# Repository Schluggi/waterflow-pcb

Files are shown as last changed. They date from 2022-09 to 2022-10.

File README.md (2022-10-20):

# waterflow-pcb


<a href="https://www.buymeacoffee.com/schluggi" target="_blank">Buy Me A Coffee</a>

## Description
I love the idea of GreatScott`s [Online Water Tracker](https://www.youtube.com/watch?v=BNK92ep8DhY), but unfortunately
it was really difficult for me to implement his circuit on a perfboard, so I designed a cheap PCB for this.

> Please notice, that this board does not replace/include the charge circuit (TP4056) or the boost converter. It
> only replaces the big ESP circuit.

The PCB has also some improvements:
- Connection terminals to easily (dis)connect everything
- Extra connection for a waterflow-sensors [with a temperature sensor](https://smile.amazon.de/gp/product/B07QNN1N7W/ref=ppx_yo_dt_b_asin_title_o04_s01)

## Images
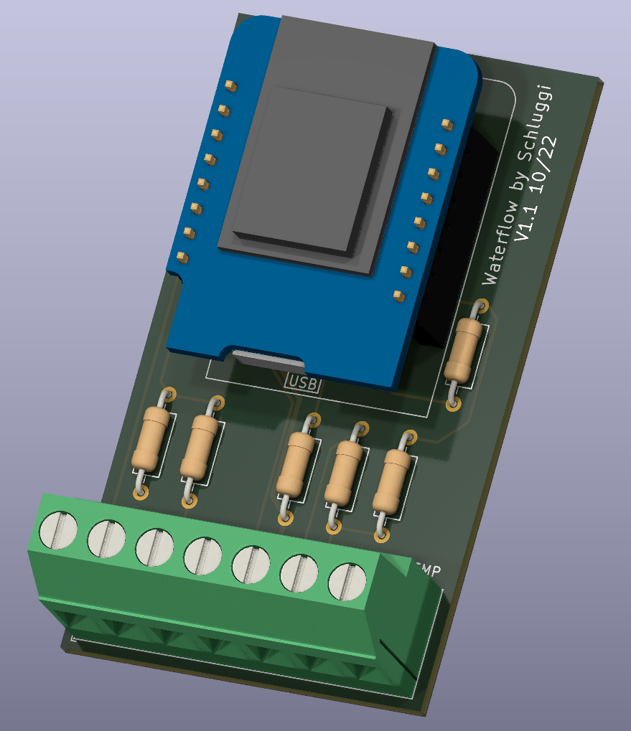
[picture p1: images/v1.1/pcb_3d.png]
[](images/v1.1/pcb_3d.png)
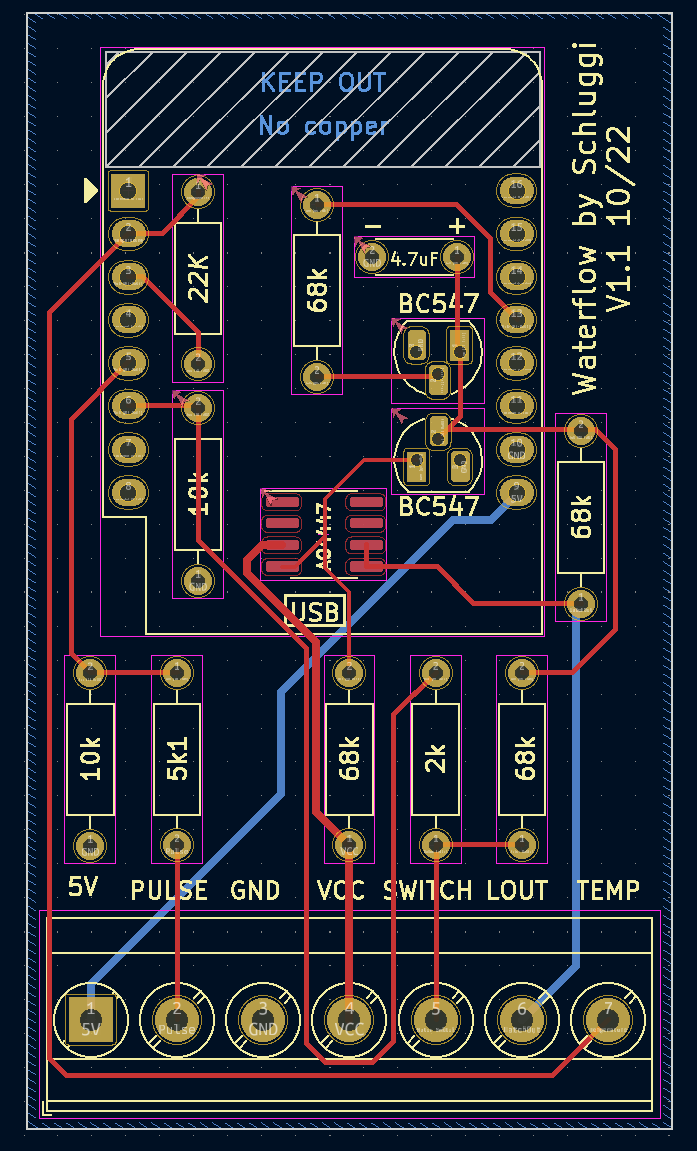
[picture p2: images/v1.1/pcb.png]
[](images/v1.1/pcb.png)
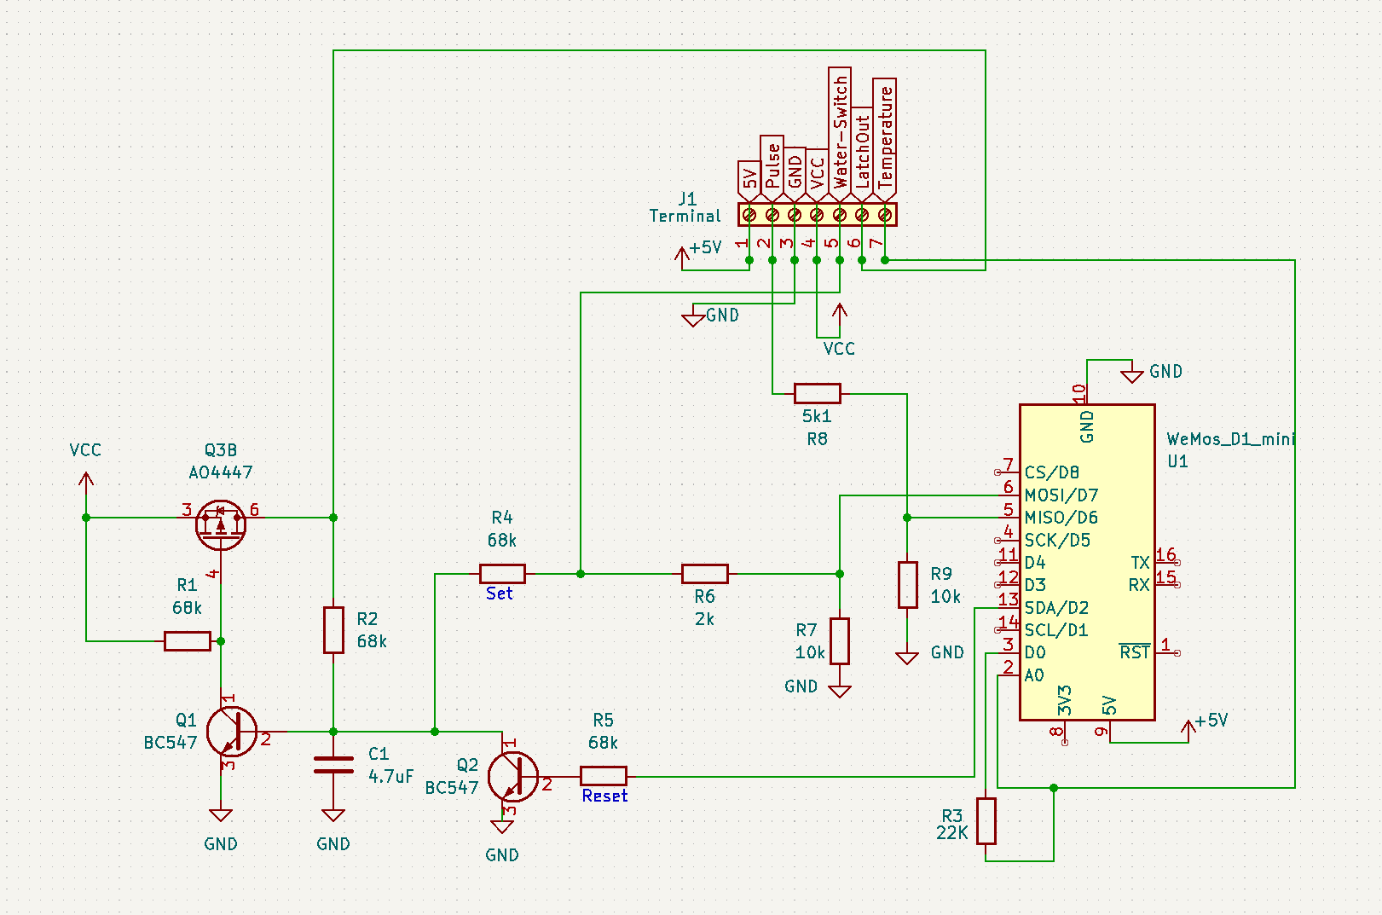
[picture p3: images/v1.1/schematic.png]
[](images/v1.1/schematic.png)

## How to order?
Before you order the PCB, make sure you have all the needed components. You can find them
[here](https://www.instructables.com/Online-Water-Tracker-Reduce-Shower-Time/). Also don't forget to 3d print the case.

Ready? Let's go. I always order my PCBs via [JLCPCB](https://jlcpcb.com), a chinese PCB manufacturer.
1. Create an account
2. Click "Order now"
3. Upload the zip file located inside the [manufactoring](manufactoring) directory
4. Optional: Choose a different color, an ECO-friendly lead-free surface finish and check that no order number is 
printed on the PCB (for aesthetic reasons).

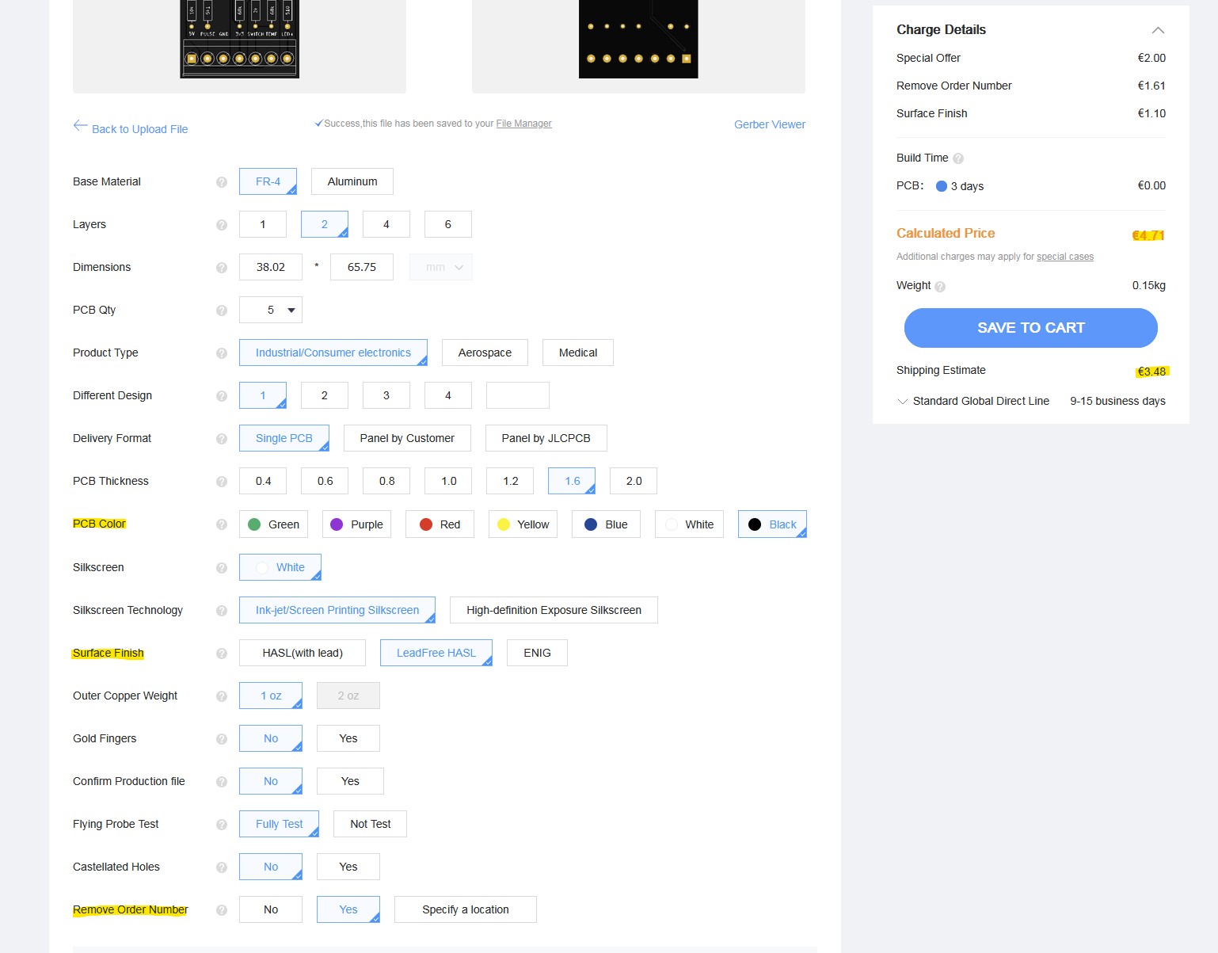
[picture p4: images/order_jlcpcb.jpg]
[](images/order_jlcpcb.jpg)

After all you got 5 PCBs for less than 10€. 

## Questions
Just open an issue :)

## Credits 
Created and maintained by Lukas Schulte-Tickmann / Schluggi.

Inspired by [GreatScott](https://www.instructables.com/member/GreatScottLab/).

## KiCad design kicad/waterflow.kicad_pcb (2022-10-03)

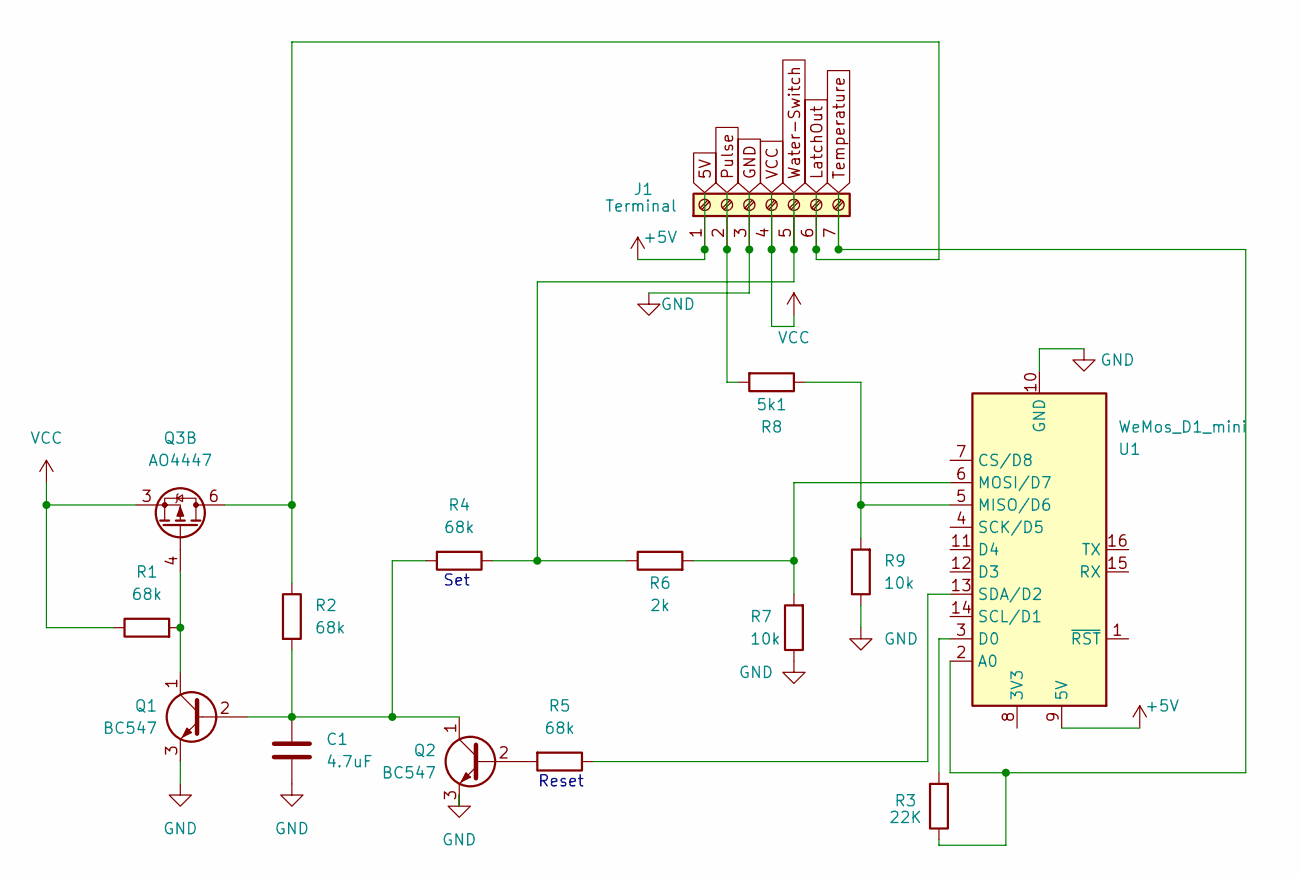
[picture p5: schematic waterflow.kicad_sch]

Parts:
C1: 4.7uF; C_Disc_D4.3mm_W1.9mm_P5.00mm
J1: Terminal; TerminalBlock_Phoenix_MKDS-3-7-5.08_1x07_P5.08mm_Horizontal
Q1, Q2: BC547; TO-92_HandSolder
Q3: AO4447; SOIC-8_3.9x4.9mm_P1.27mm
R1, R2, R4, R5: 68k; R_Axial_DIN0207_L6.3mm_D2.5mm_P10.16mm_Horizontal
R3: 22K; R_Axial_DIN0207_L6.3mm_D2.5mm_P10.16mm_Horizontal
R6: 2k; R_Axial_DIN0207_L6.3mm_D2.5mm_P10.16mm_Horizontal
R7, R9: 10k; R_Axial_DIN0207_L6.3mm_D2.5mm_P10.16mm_Horizontal
R8: 5k1; R_Axial_DIN0207_L6.3mm_D2.5mm_P10.16mm_Horizontal
U1: WeMos_D1_mini; WEMOS_D1_mini_light

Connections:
5V: J1.1, U1.9 (5V)
GND: C1.2, J1.3, Q1.3 (E), Q2.3 (E), R7.1, R9.1, U1.10 (GND)
LatchOut: J1.6, Q3.5 (D), Q3.6 (D), R2.1
unnamed: C1.1, Q1.2 (B), Q2.1 (C), R2.2, R4.2
unnamed: Q1.1 (C), Q3.4 (G), R1.2
unnamed: Q2.2 (B), R5.2
unnamed: R3.2, U1.3 (D0)
unnamed: R5.1, U1.13 (SDA/D2)
unnamed: R6.2, R7.2, U1.6 (MOSI/D7)
unnamed: R8.1, R9.2, U1.5 (MISO/D6)
Pulse: J1.2, R8.2
Temperature: J1.7, R3.1, U1.2 (A0)
VCC: J1.4, Q3.3 (1), R1.1
Water-Switch: J1.5, R4.1, R6.1

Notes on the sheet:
Set
Reset

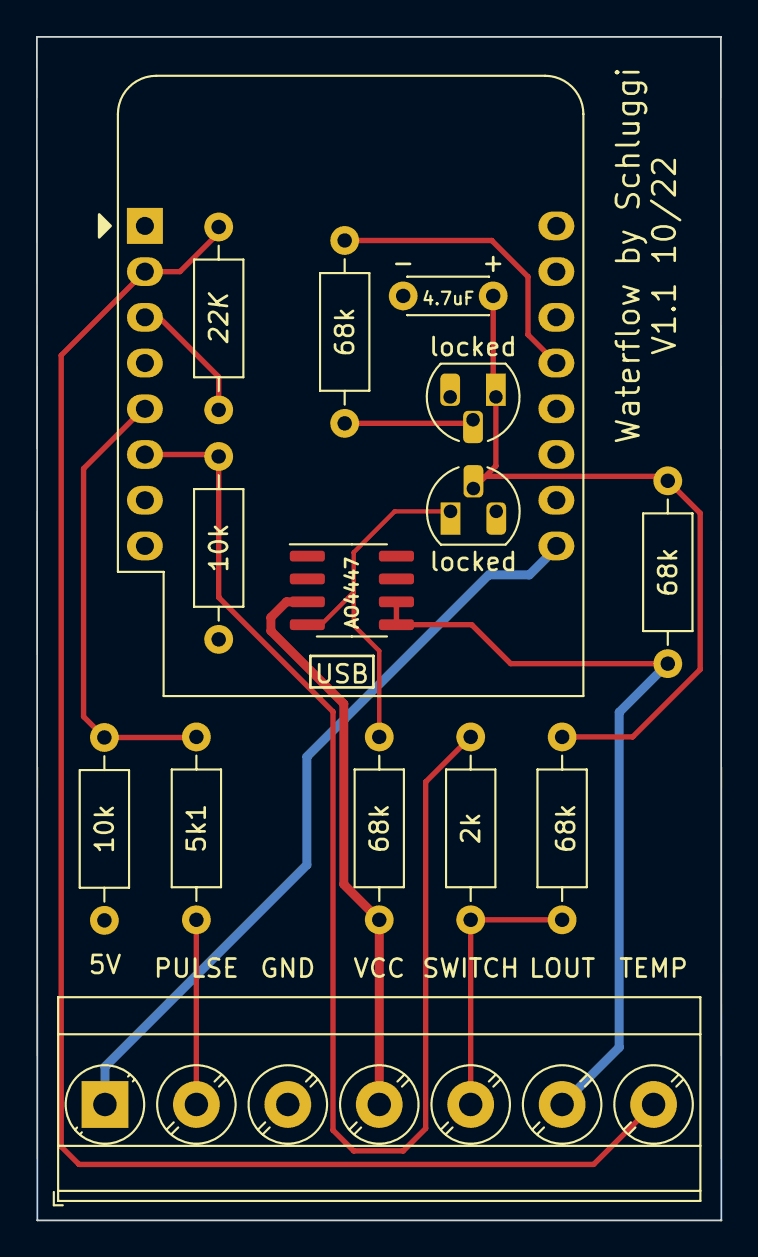
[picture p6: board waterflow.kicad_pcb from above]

Board: 2 copper layers, 38.0 x 65.8 mm, 15 parts (0 on the bottom side), 14 nets.

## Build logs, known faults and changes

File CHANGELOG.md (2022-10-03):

## v1.1
- added: esphome example file
- added: labels of the D1 mini
- fixed: LED+ is now LOUT
- fixed: temp sensor now works

## v1.0
The first release.

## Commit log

2022-09-16 first release
    [waterflow.kicad_pcb, waterflow.kicad_sch]
2022-09-16 added: circuit note in readme
2022-09-25 fixed: LED+ is now LOUT
    [waterflow.kicad_pcb, waterflow.kicad_sch]
2022-09-25 added: polarity labels for C1
    [waterflow.kicad_pcb]
2022-09-25 changed: footprint for BC547 (make soldering easier)
    [waterflow.kicad_pcb, waterflow.kicad_sch]
2022-09-25 removed: duplicated connector label
    [waterflow.kicad_sch]
2022-09-28 added: usb label for orientation
    [waterflow.kicad_pcb]
2022-09-28 changed: label 3V3 -> VCC
    [waterflow.kicad_pcb, waterflow.kicad_sch]
2022-10-03 added: some kicad files to ignore
2022-10-03 release v1.1
    [waterflow.kicad_pcb, waterflow.kicad_sch]
2022-10-14 fixed: PCB improvement text

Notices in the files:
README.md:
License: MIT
